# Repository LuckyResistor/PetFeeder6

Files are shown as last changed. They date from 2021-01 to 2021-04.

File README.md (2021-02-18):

# Files for the Pet-Feeder 6 Project

## Details

You will find all details of this project here:

https://luckyresistor.me/projects/lets-print-a-cat-pet-feeding-device/

## License

https://creativecommons.org/licenses/by-sa/4.0/

<br />This work is licensed under a <a rel="license" href="http://creativecommons.org/licenses/by/4.0/">Creative Commons Attribution 4.0 International License</a>.

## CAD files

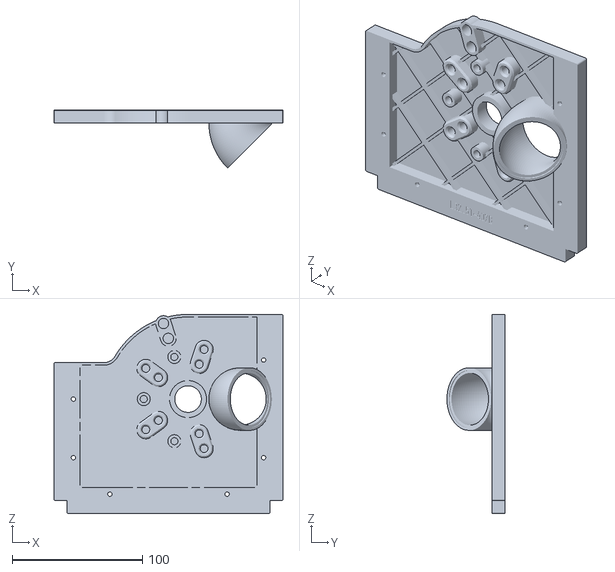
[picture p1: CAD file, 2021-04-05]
mechanics/LR2051-407B.stl
175.8 x 44.6 x 152.9

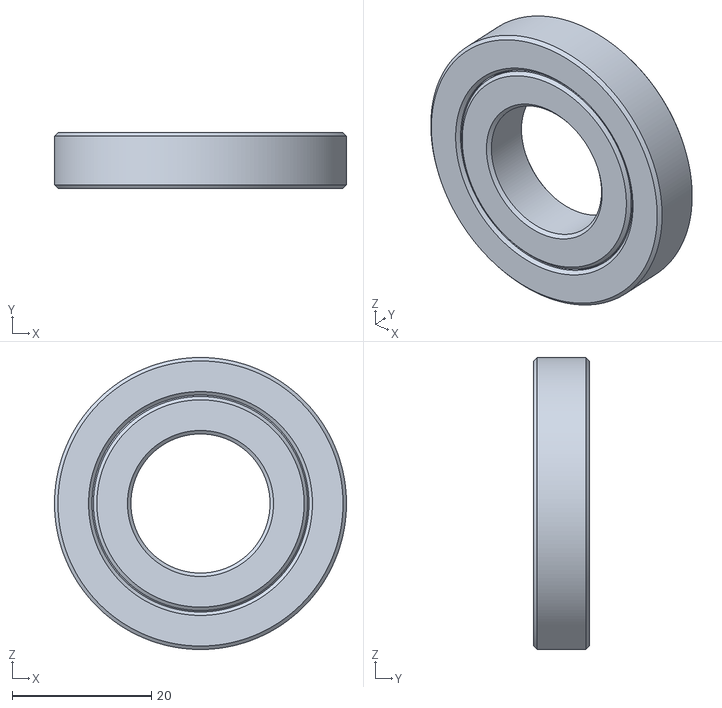
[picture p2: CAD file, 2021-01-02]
mechanics/mockups/LR2051-822.stl
42.0 x 8.00 x 42.0

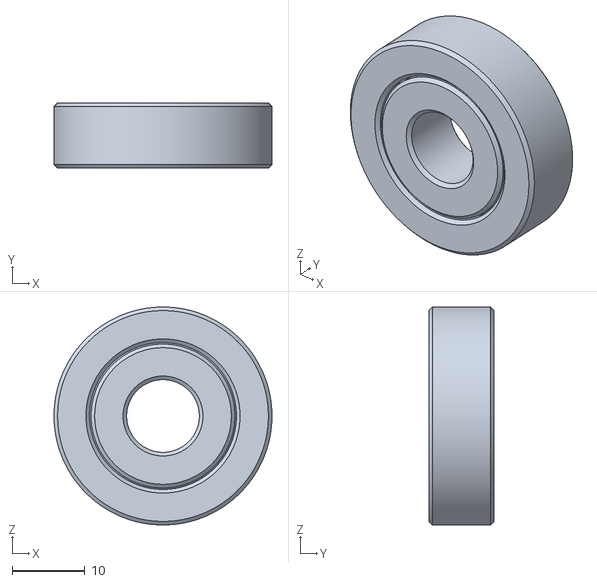
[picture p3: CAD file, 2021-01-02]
mechanics/mockups/LR2051-821.stl
30.0 x 9.00 x 30.0

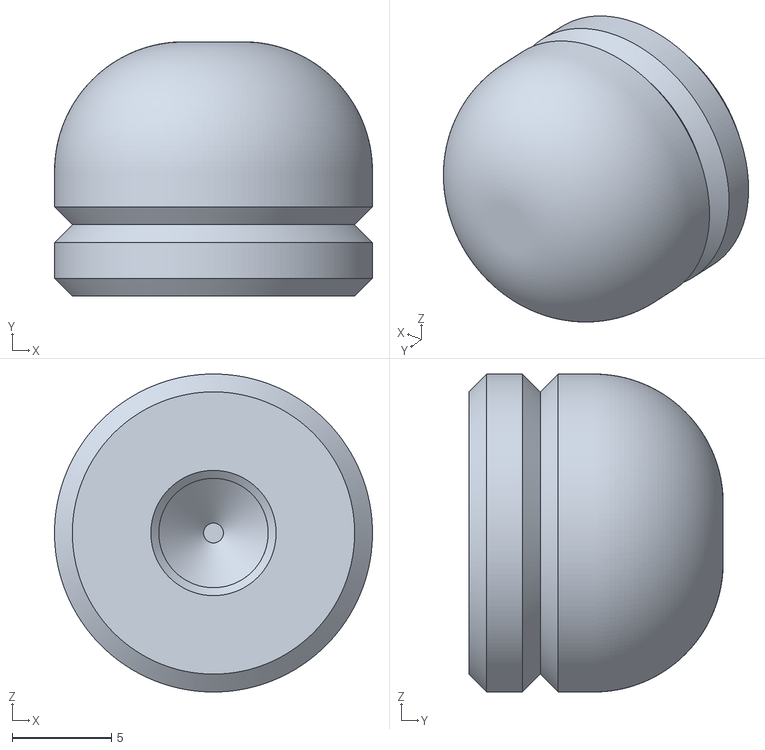
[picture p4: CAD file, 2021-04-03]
mechanics/LR2051-412B.stl
16.0 x 12.8 x 16.0

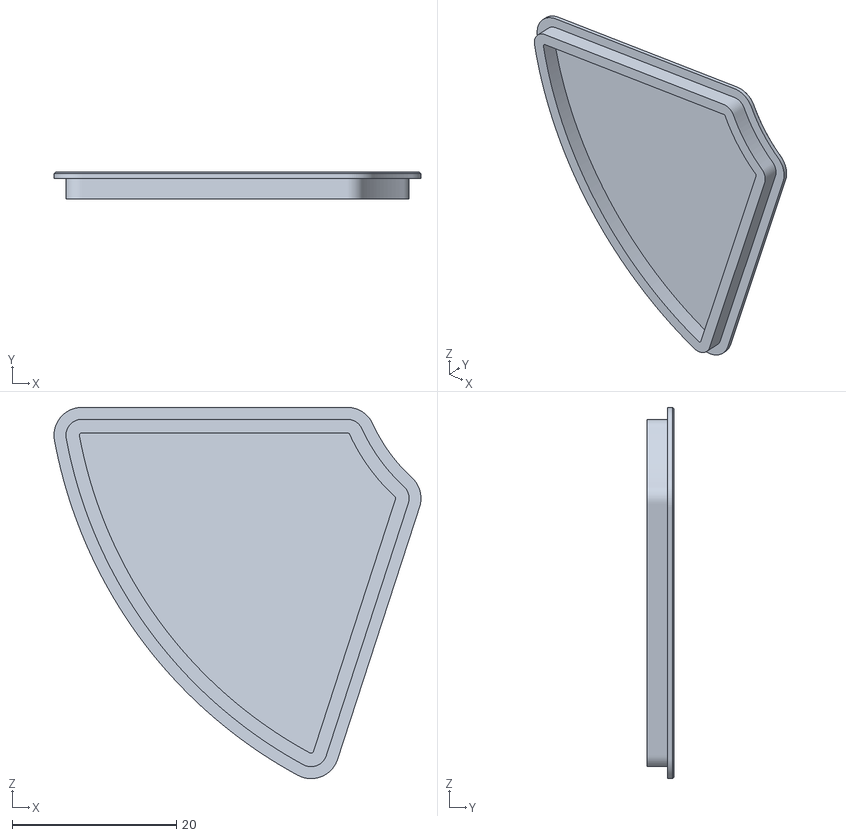
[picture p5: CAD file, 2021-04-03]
mechanics/LR2051-413A.stl
44.6 x 3.30 x 45.1

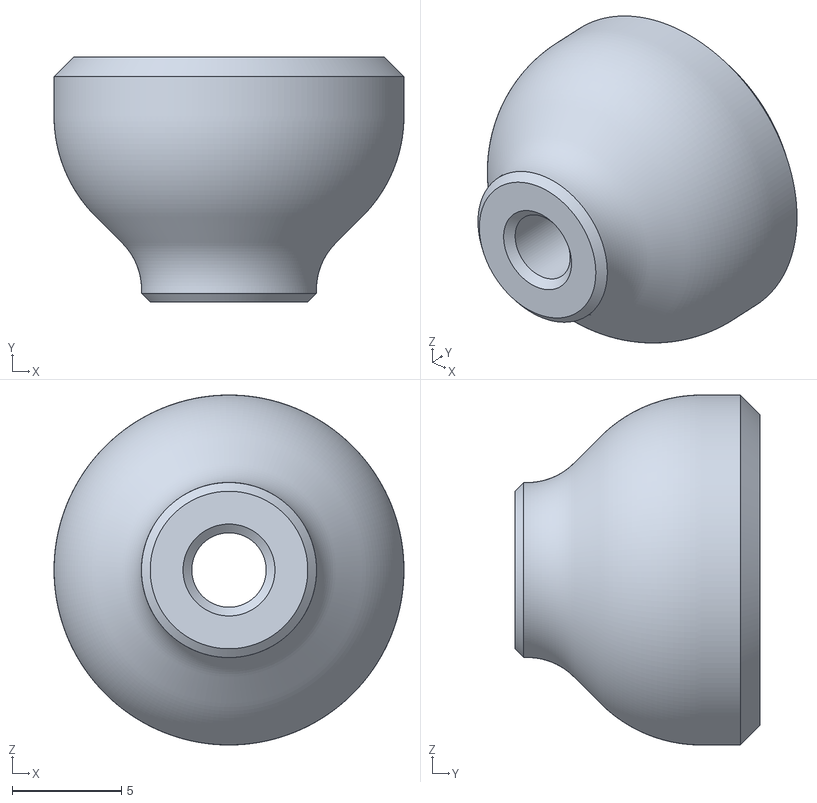
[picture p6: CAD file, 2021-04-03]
mechanics/LR2051-411B.stl
16.0 x 11.2 x 16.0

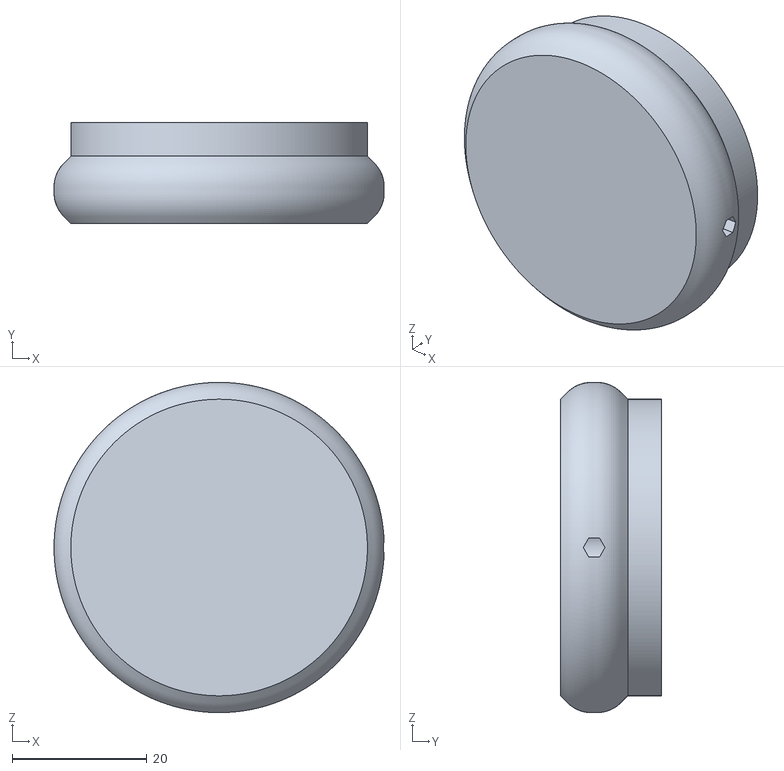
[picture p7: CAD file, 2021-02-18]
mechanics/LR2051-421A.stl
49.0 x 15.0 x 49.0

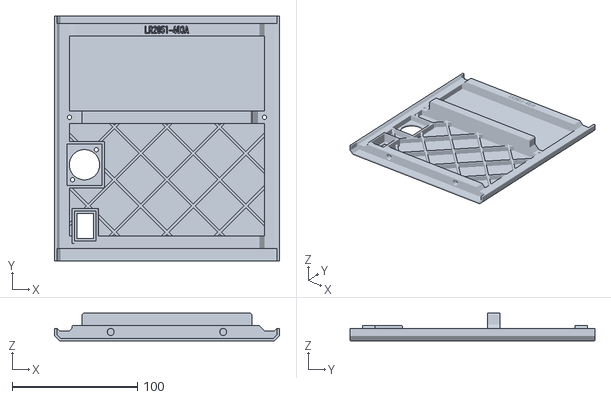
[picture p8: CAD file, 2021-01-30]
mechanics/LR2051-403A.stl
180.0 x 195.9 x 22.0

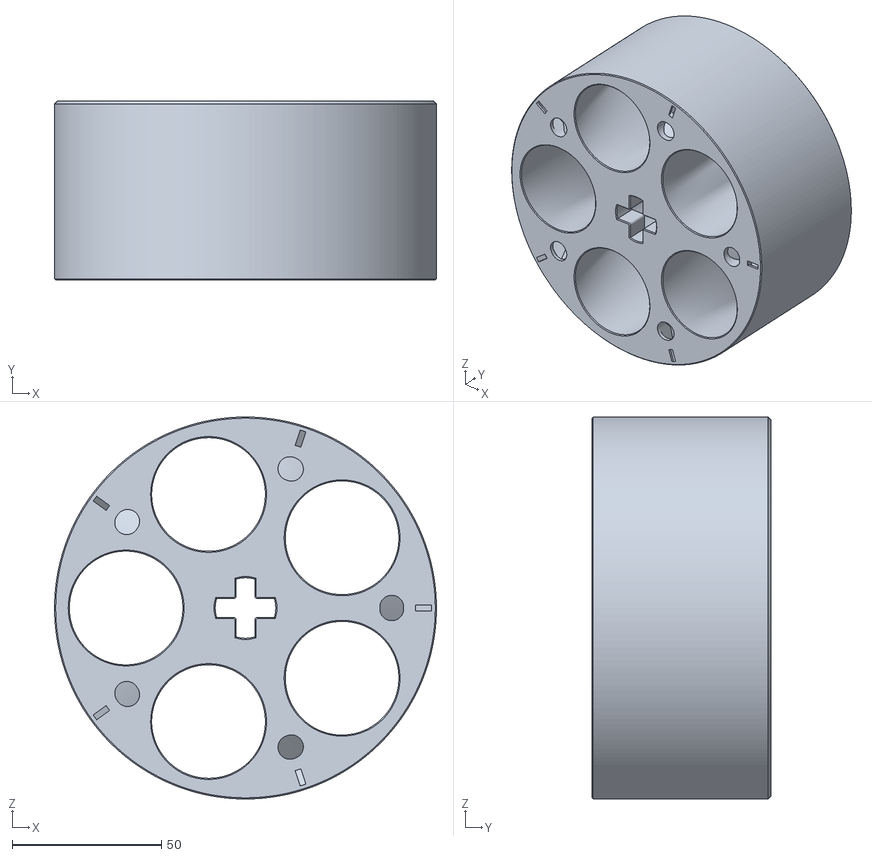
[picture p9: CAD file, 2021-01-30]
mechanics/LR2051-501.stl
128.0 x 60.0 x 128.0

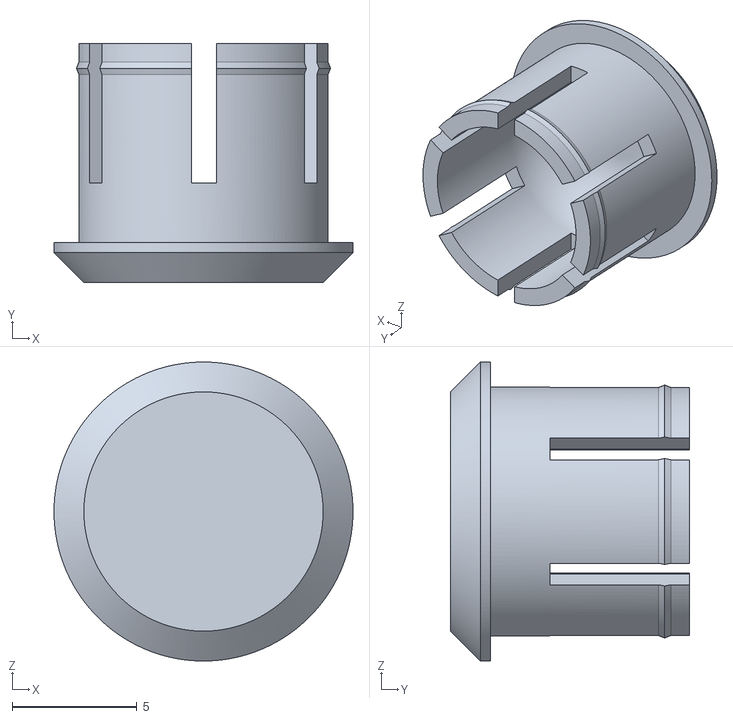
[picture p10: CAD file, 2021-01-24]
mechanics/LR2051-422.stl
12.0 x 9.60 x 12.0

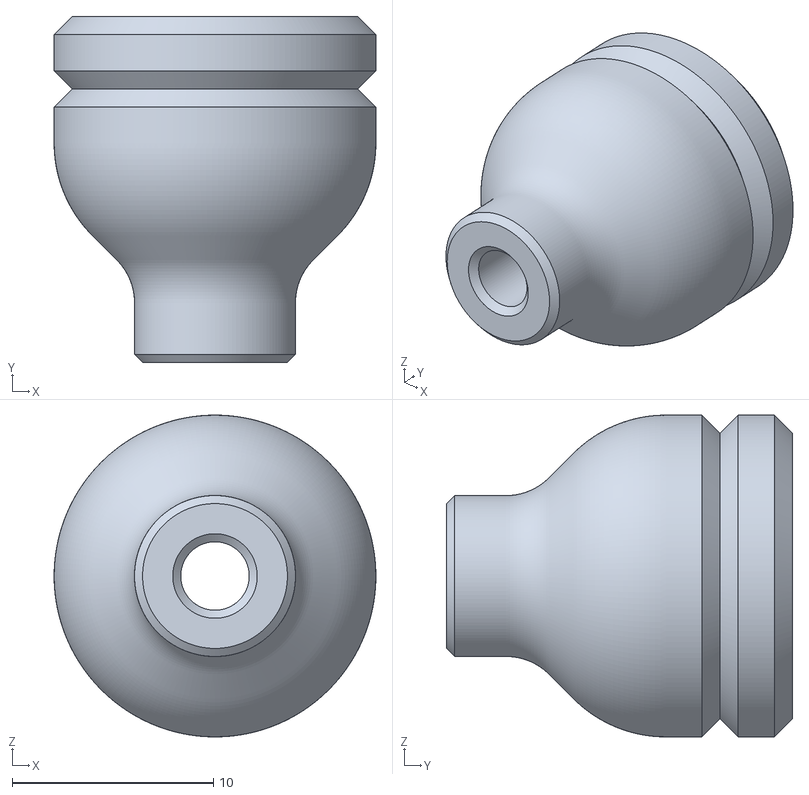
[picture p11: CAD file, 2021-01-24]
mechanics/LR2051-411A.stl
16.0 x 17.2 x 16.0

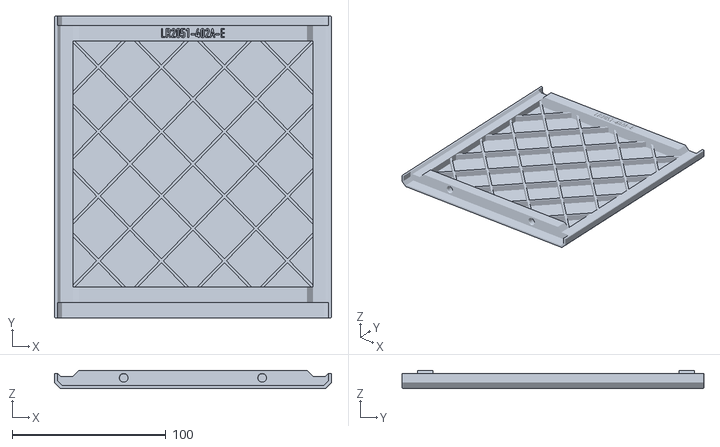
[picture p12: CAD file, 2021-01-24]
mechanics/LR2051-402A-E.stl
180.0 x 195.9 x 12.0

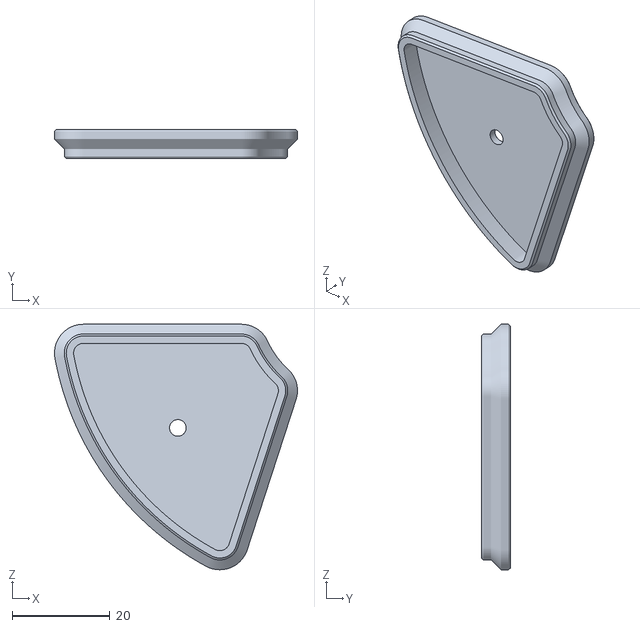
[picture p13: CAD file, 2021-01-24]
mechanics/LR2051-409A.stl
49.6 x 6.00 x 50.1

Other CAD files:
slicer-files/LR2051-407B.3mf
mechanics/LR2051-407E.stl
slicer-files/LR2051-407E.3mf
mechanics/LR2051-403A-E.stl
mechanics/LR2051-402A-ND.stl
mechanics/LR2051-101B.stl
mechanics/LR2051-102B.stl
mechanics/LR2051-103B.stl
mechanics/LR2051-104B.stl
mechanics/LR2051-105B.stl
mechanics/LR2051-107B.stl
mechanics/LR2051-108B.stl
mechanics/LR2051-111B.stl
mechanics/LR2051-112B.stl
mechanics/LR2051-121.stl
mechanics/LR2051-122.stl
mechanics/LR2051-123.stl
mechanics/LR2051-124.stl
mechanics/LR2051-401A.stl
mechanics/LR2051-402A.f3d
mechanics/LR2051-402A.stl
mechanics/LR2051-403A.f3d
mechanics/LR2051-404A.stl
mechanics/LR2051-405A.stl
mechanics/LR2051-406A.stl
mechanics/LR2051-407A.stl
mechanics/LR2051-408A.stl
mechanics/LR2051-412A.stl
mechanics/mockups/LR2051-821.f3d
mechanics/mockups/LR2051-822.f3d
mechanics/old-revisions/LR2051-407A.stl
mechanics/old-revisions/LR2051-412A.stl

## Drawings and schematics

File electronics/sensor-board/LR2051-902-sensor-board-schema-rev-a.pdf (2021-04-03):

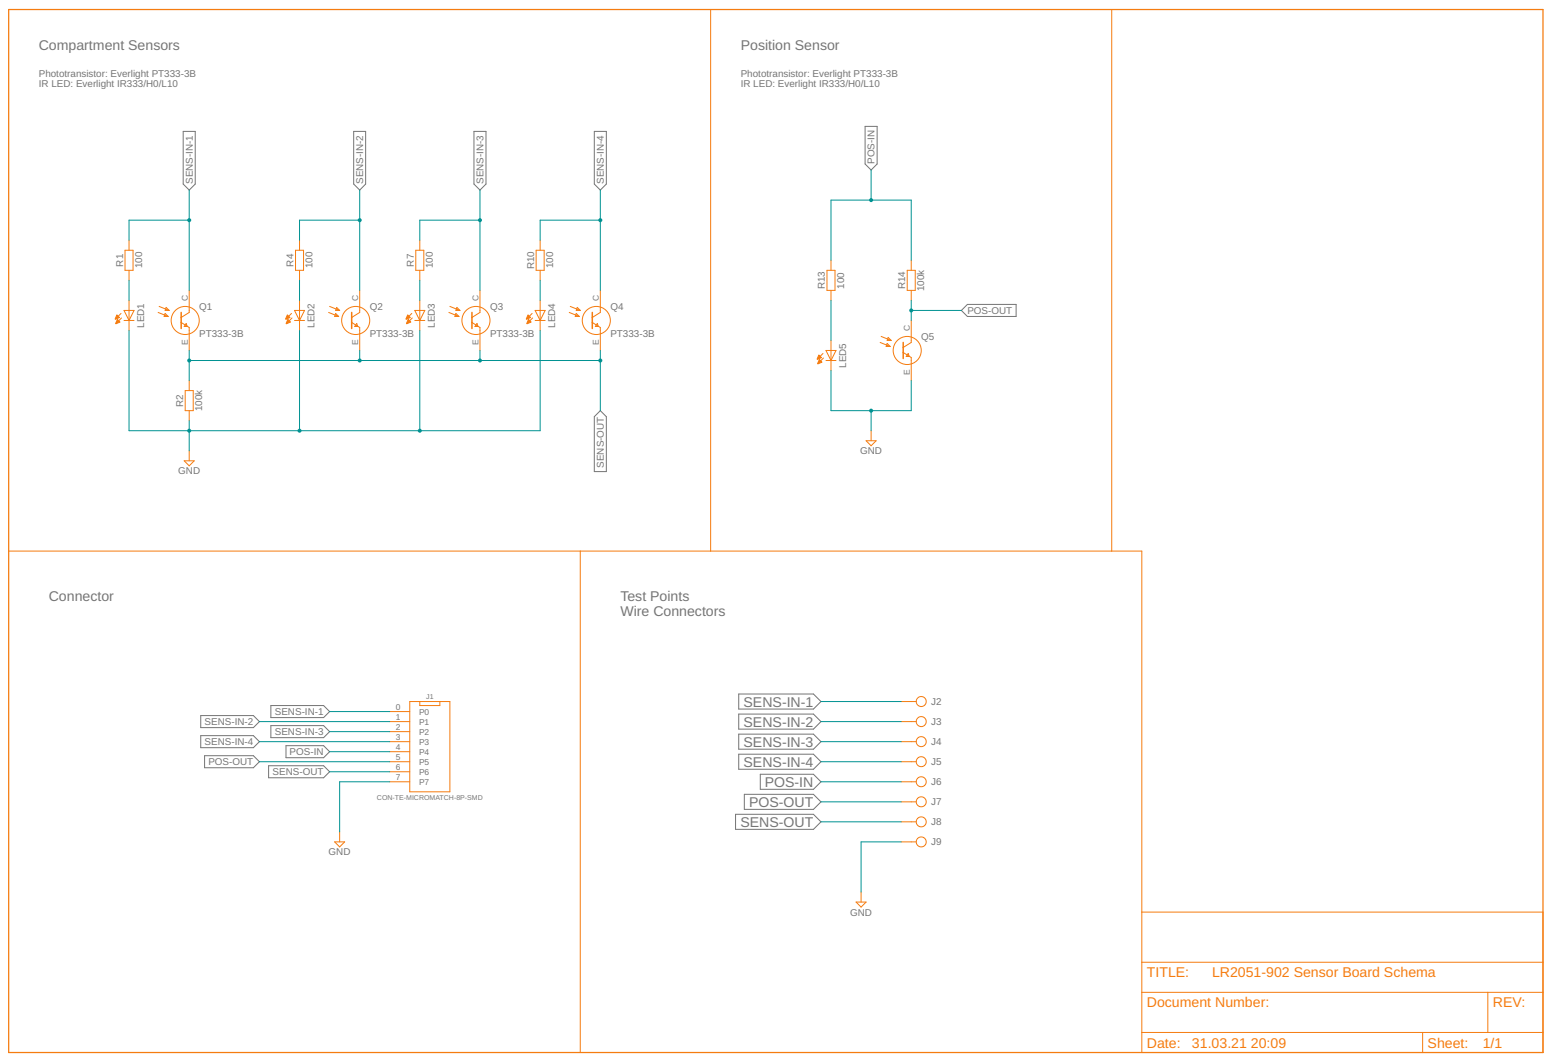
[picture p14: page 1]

SENS-IN-1

CON-TE-MICROMATCH-8P-SMD GND

Document Number: | REV:

Date: 31.03.21 20:09 | Sheet: 1/1

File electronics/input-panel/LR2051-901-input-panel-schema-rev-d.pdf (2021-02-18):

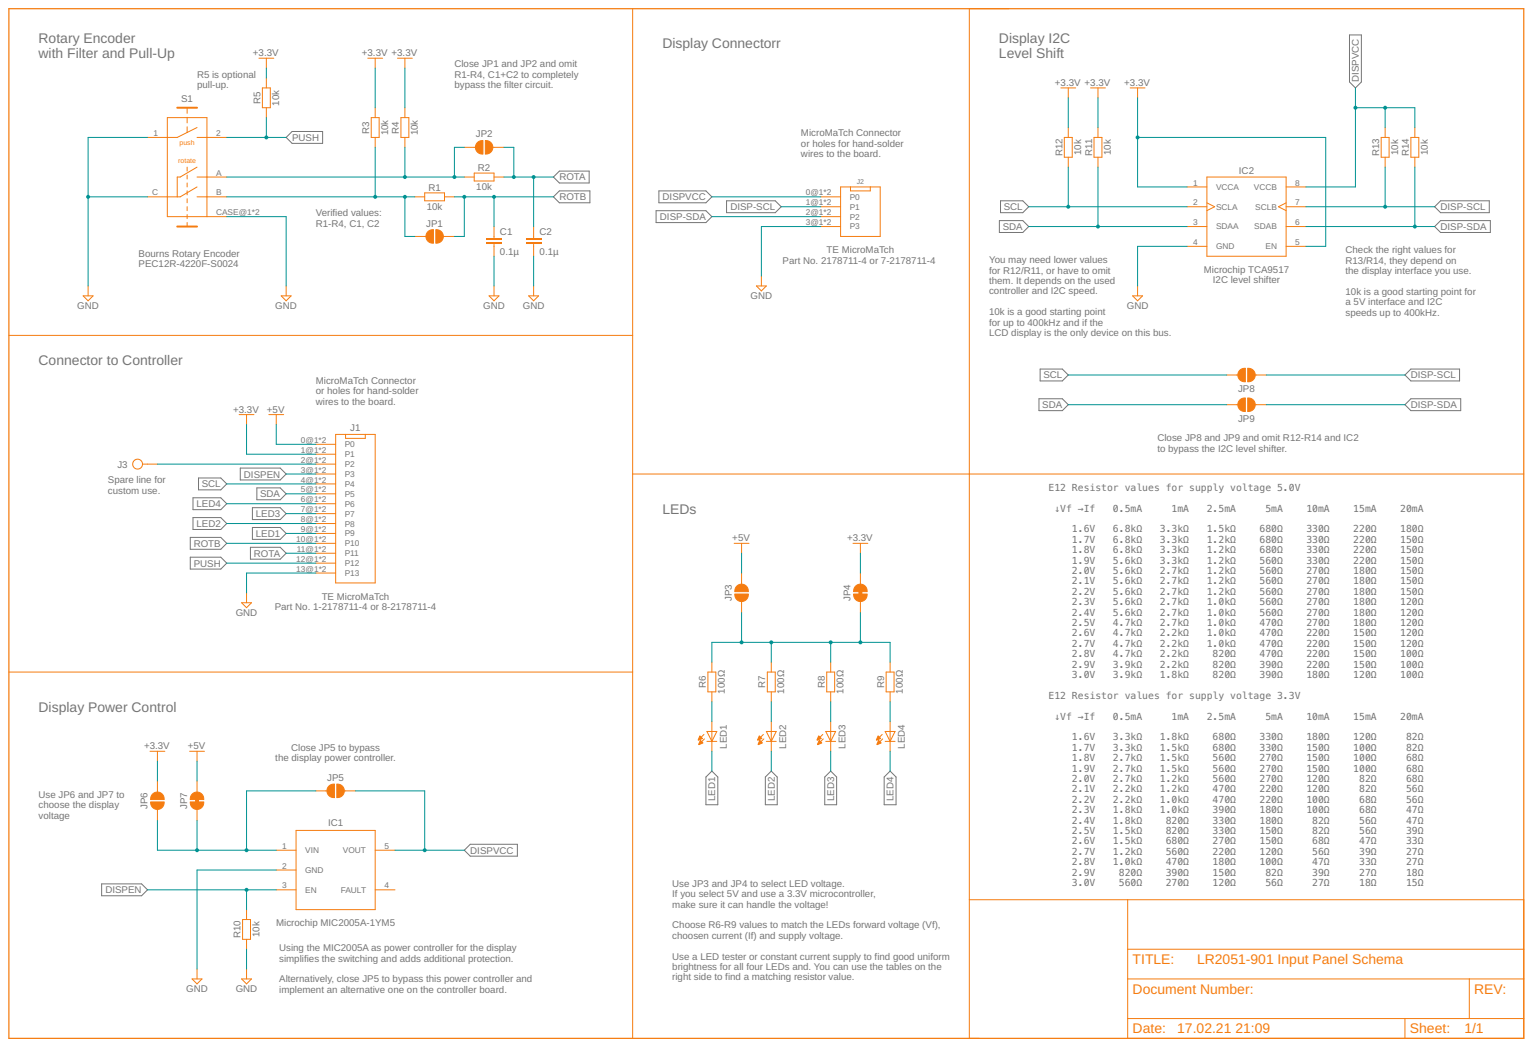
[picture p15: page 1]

Rotary Encoder
with Filter and Pull-Up

Close JP1 and JP2 and omit
R1-R4, C1+C2 to completely

bypass the filter circuit. R5 is optional
pull-up.

MicroMaTch Connector or holes for hand-solder wires to the board.

Check the right values for R13/R14, they depend on
the display interface you use. 10k is a good starting point for a 5V interface and I2C

I2C level shifter You may need lower values
for R12/R11, or have to omit
them. It depends on the used
controller and I2C speed. 10k is a good starting point

for up to 400kHz and if the
LCD display is the only device on this bus.

MicroMaTch Connector or holes for hand-solder wires to the board. Spare line for custom use.

Close JP8 and JP9 and omit R12-R14 and IC2
to bypass the I2C level shifter.

E12 Resistor values for supply voltage 5.0V
E12 Resistor values for supply voltage 3.3V

Close JP5 to bypass
the display power controller.

Use JP3 and JP4 to select LED voltage.
If you select 5V and use a 3.3V microcontroller, make sure it can handle the voltage!

Choose R6-R9 values to match the LEDs forward voltage (Vf), choosen current (If) and supply voltage. Use a LED tester or constant current supply to find good uniform

Using the MIC2005A as power controller for the display
simplifies the switching and adds additional protection. Alternatively, close JP5 to bypass this power controller and

brightness for all four LEDs and. You can use the tables on the
right side to find a matching resistor value.

implement an alternative one on the controller board.

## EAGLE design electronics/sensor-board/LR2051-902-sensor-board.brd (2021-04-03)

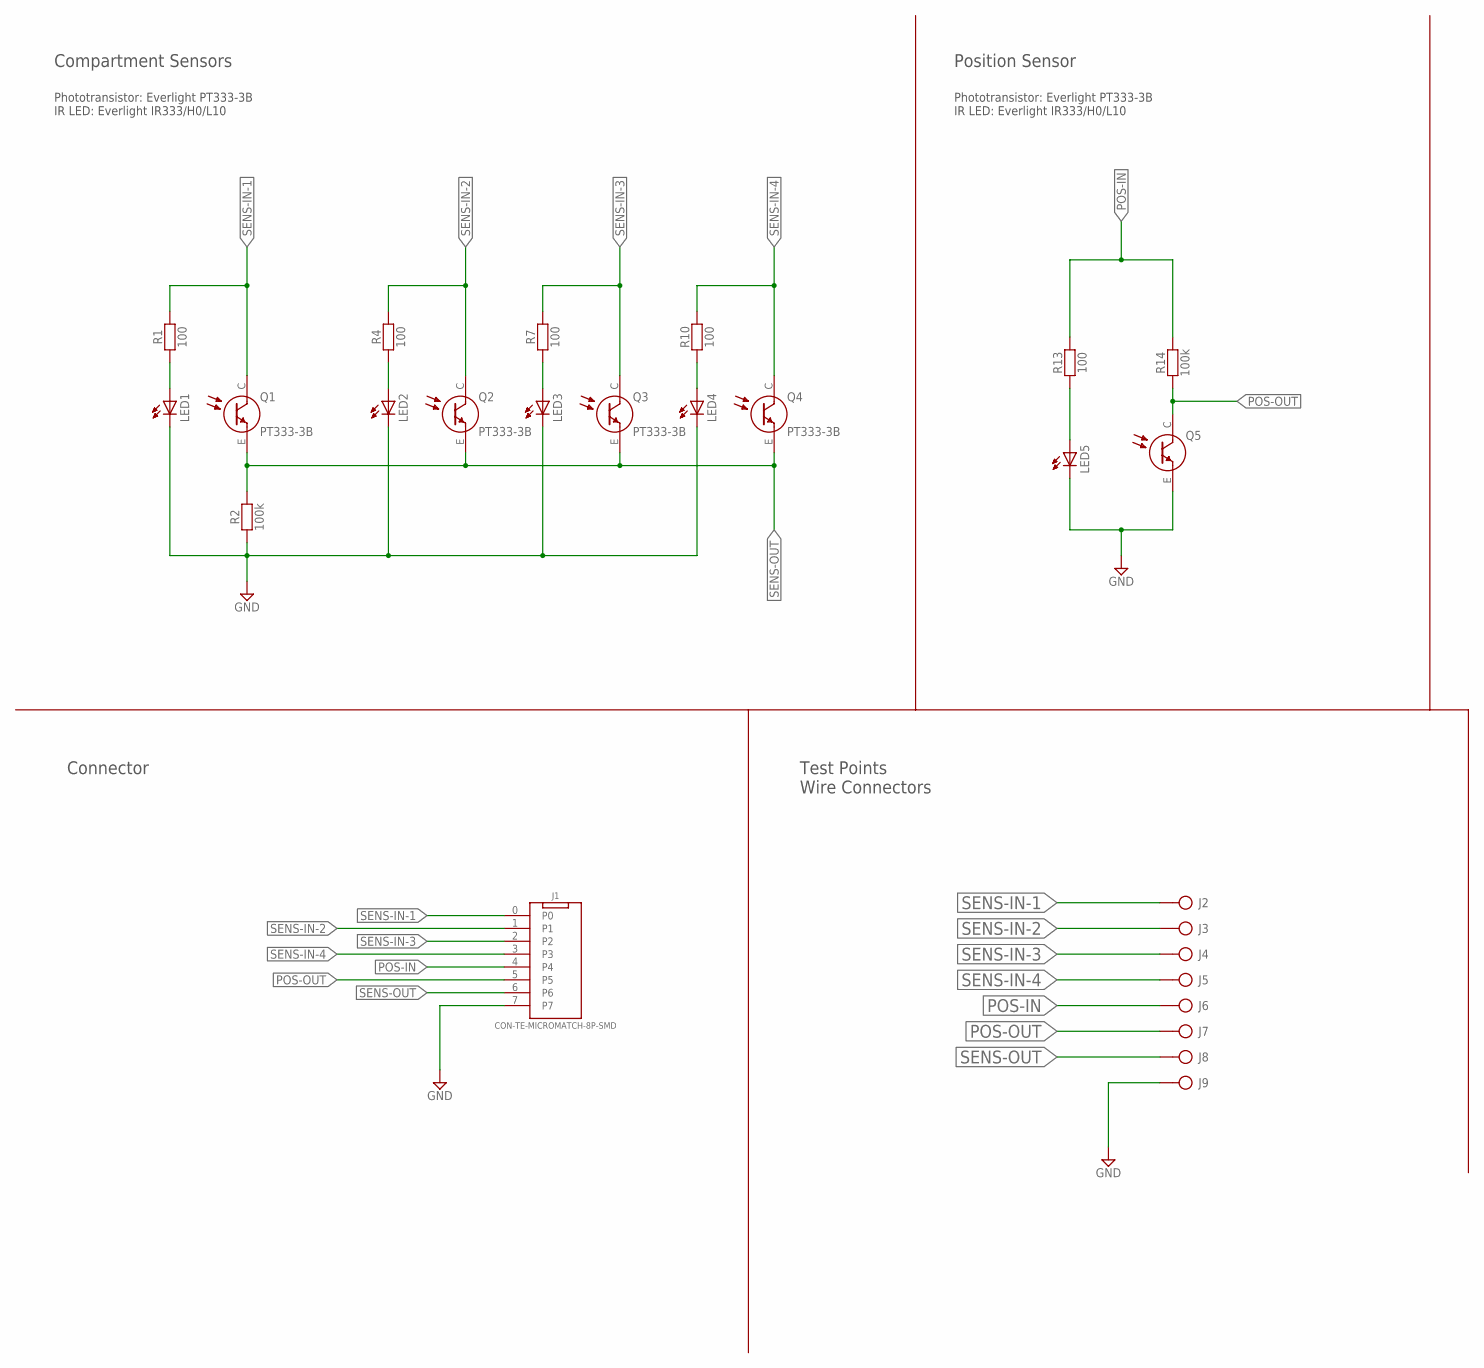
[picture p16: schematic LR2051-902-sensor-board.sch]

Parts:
J1: CON-TE-MICROMATCH-8P-SMD; CON-TE-MICROMATCH-2178711-8
J2, J3, J4, J5, J6, J7, J8, J9: CON-HOLE-D0.9
LED1, LED2, LED3, LED4, LED5: LED5MM
Q1, Q2, Q3, Q4: PT333-3B; Q-PHOTO-2P-TH-5MM
Q5: Q-PHOTO-TH-5MM; Q-PHOTO-2P-TH-5MM
R1, R4, R7, R10, R13: 100; R-0805-HANDSOLDER
R2, R14: 100k; R-0805-HANDSOLDER

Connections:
GND: J1.7, J9.1, LED1.K (C), LED2.K (C), LED3.K (C), LED4.K (C), LED5.K (C), Q5.E, R2.1
unnamed: LED1.A, R1.1
unnamed: LED2.A, R4.1
unnamed: LED3.A, R7.1
unnamed: LED4.A, R10.1
unnamed: LED5.A, R13.1
POS-IN: J1.4, J6.1, R13.2, R14.2
POS-OUT: J1.5, J7.1, Q5.C, R14.1
SENS-IN-1: J1.0, J2.1, Q1.C, R1.2
SENS-IN-2: J1.1, J3.1, Q2.C, R4.2
SENS-IN-3: J1.2, J4.1, Q3.C, R7.2
SENS-IN-4: J1.3, J5.1, Q4.C, R10.2
SENS-OUT: J1.6, J8.1, Q1.E, Q2.E, Q3.E, Q4.E, R2.2

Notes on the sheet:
Compartment Sensors
Position Sensor
Connector
Test Points Wire Connectors
Phototransistor: Everlight PT333-3B IR LED: Everlight IR333/H0/L10

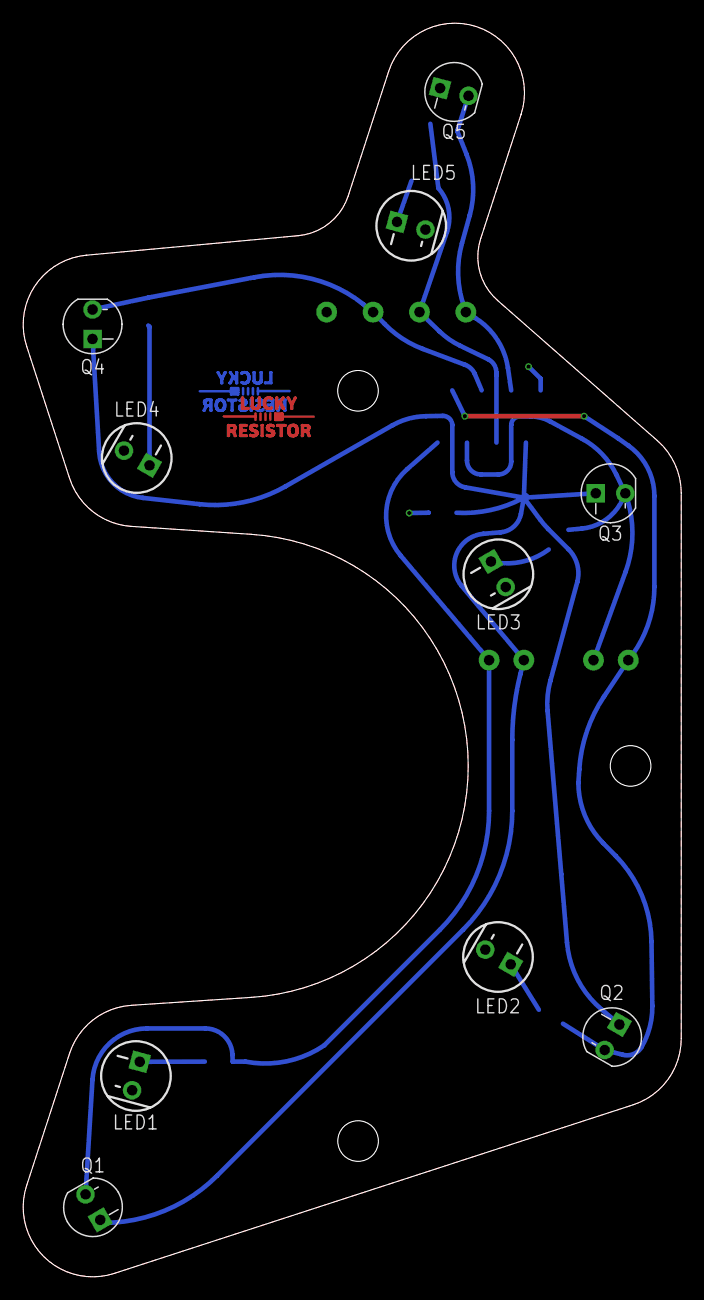
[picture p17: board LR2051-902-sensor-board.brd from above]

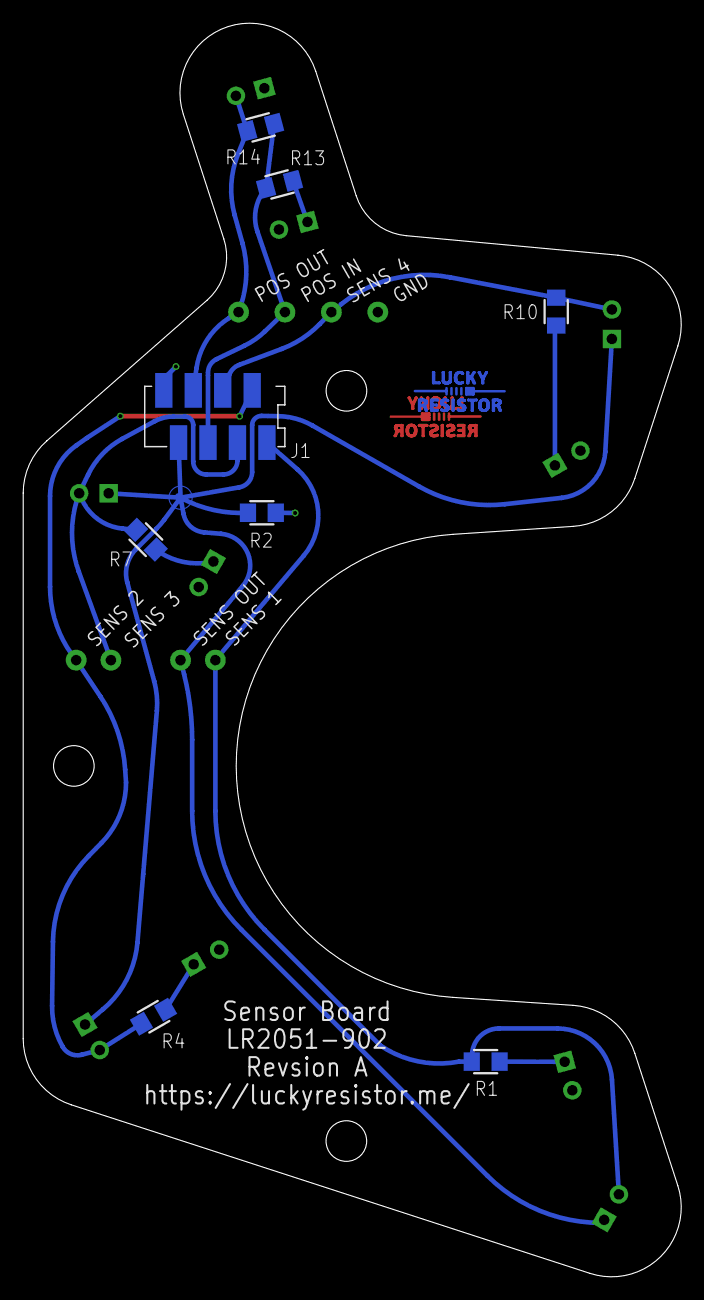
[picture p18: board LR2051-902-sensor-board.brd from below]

Board: 2 copper layers, 56.7 x 108.1 mm, 28 parts (17 on the bottom side), 13 nets.

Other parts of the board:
U$1, U$2: LR_LOGO_COPPER_8MM_NOMASK

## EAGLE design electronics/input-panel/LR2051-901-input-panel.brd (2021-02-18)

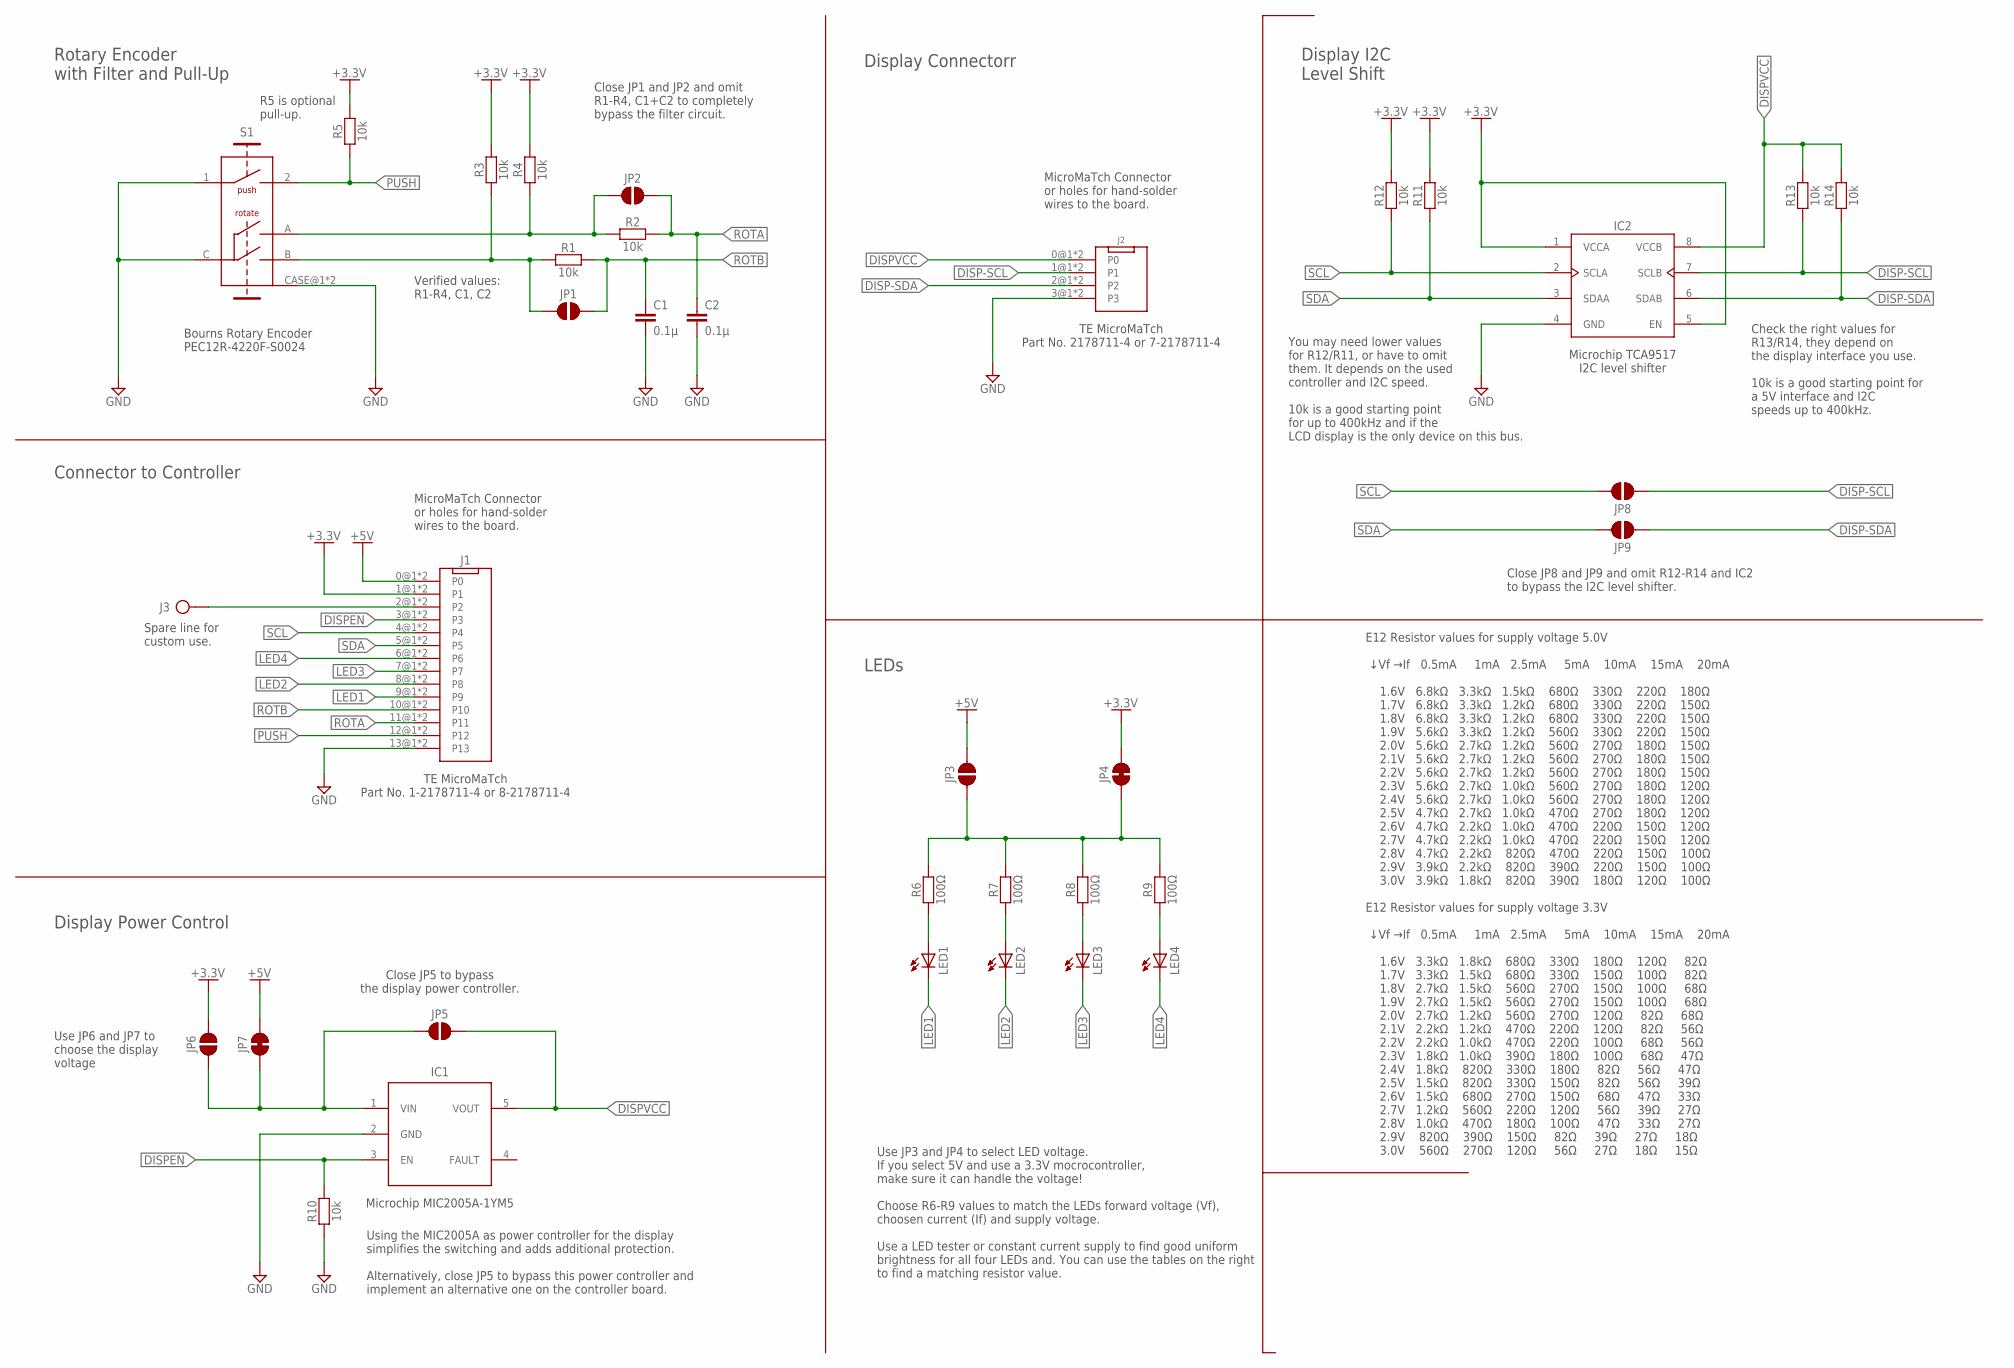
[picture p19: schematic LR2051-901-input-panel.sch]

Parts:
C1, C2: 0.1µ; CAPACITOR-0805-VISHAY
IC1: IC-MIC2005A-1YM5; SOT23-5
IC2: IC-TCA9517; SOIC127P599X175-8N
J1: CON-TE-MICROMATCH-14P-SMD+TH; CON-TE-MICROMATCH-1-2178711-4+TH
J2: CON-TE-MICROMATCH-4P-SMD+TH; CON-TE-MICROMATCH-2178711-4+TH
J3: CON-HOLE-D0.9
JP1, JP2, JP3, JP5, JP6, JP8, JP9: J-SMD-OFF
JP4, JP7: J-SMD-ON
LED1, LED2, LED3, LED4: LED5MM
R1, R2, R3, R4, R5, R10, R11, R12, R13, R14: 10k; R-0805-HANDSOLDER
R6, R7, R8, R9: 100Ω; R-0805-HANDSOLDER
S1: ENC-BOURNS-PEC12R-4220F-S0024

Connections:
+3.3V: IC2.1 (VCCA), IC2.5 (EN), J1.1@1 (P1), J1.1@2 (P1), JP4.2, JP6.2, R3.2, R4.2, R5.2, R11.2, R12.2
+5V: J1.0@1 (P0), J1.0@2 (P0), JP3.2, JP7.2
DISP-SCL: IC2.7 (SCLB), J2.1@1 (P1), J2.1@2 (P1), JP8.1, R13.1
DISP-SDA: IC2.6 (SDAB), J2.2@1 (P2), J2.2@2 (P2), JP9.1, R14.1
DISP-VIN: IC1.1 (VIN), JP5.1, JP6.1, JP7.1
DISPEN: IC1.3 (EN), J1.3@1 (P3), J1.3@2 (P3), R10.2
DISPVCC: IC1.5 (VOUT), IC2.8 (VCCB), J2.0@1 (P0), J2.0@2 (P0), JP5.2, R13.2, R14.2
GND: C1.2, C2.2, IC1.2 (GND), IC2.4 (GND), J1.13@1 (P13), J1.13@2 (P13), J2.3@1 (P3), J2.3@2 (P3), R10.1, S1.1 (S), S1.C, S1.CASE@1 (GND), S1.CASE@2 (GND)
LED1: J1.9@1 (P9), J1.9@2 (P9), LED1.K (C)
LED2: J1.8@1 (P8), J1.8@2 (P8), LED2.K (C)
LED3: J1.7@1 (P7), J1.7@2 (P7), LED3.K (C)
LED4: J1.6@1 (P6), J1.6@2 (P6), LED4.K (C)
LED-VCC: JP3.1, JP4.1, R6.2, R7.2, R8.2, R9.2
unnamed: JP1.1, R1.1, R3.1, S1.B
unnamed: J1.2@1 (P2), J1.2@2 (P2), J3.1
unnamed: JP2.1, R2.1, R4.1, S1.A
unnamed: LED1.A, R6.1
unnamed: LED2.A, R7.1
unnamed: LED3.A, R8.1
unnamed: LED4.A, R9.1
PUSH: J1.12@1 (P12), J1.12@2 (P12), R5.1, S1.2 (S)
ROTA: C2.1, J1.11@1 (P11), J1.11@2 (P11), JP2.2, R2.2
ROTB: C1.1, J1.10@1 (P10), J1.10@2 (P10), JP1.2, R1.2
SCL: IC2.2 (SCLA), J1.4@1 (P4), J1.4@2 (P4), JP8.2, R12.1
SDA: IC2.3 (SDAA), J1.5@1 (P5), J1.5@2 (P5), JP9.2, R11.1

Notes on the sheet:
Rotary Encoder with Filter and Pull-Up
Connector to Controller
LEDs
Display Power Control
Display I2C Level Shift
Display Connectorr
MicroMaTch Connector or holes for hand-solder wires to the board.
Spare line for custom use.
Close JP1 and JP2 and omit R1-R4, C1+C2 to completely bypass the filter circuit.
R5 is optional pull-up.
Bourns Rotary Encoder PEC12R-4220F-S0024
Use JP3 and JP4 to select LED voltage. If you select 5V and use a 3.3V mocrocontroller, make sure it can handle the voltage\! Choose R6-R9 values to match the LEDs forward voltage (Vf), choosen current (If) and supply voltage. Use a LED tester or constant current supply to find good uniform brightn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
Microchip TCA9517 I2C level shifter
You may need lower values for R12/R11, or have to omit them. It depends on the used controller and I2C speed. 10k is a good starting point for up to 400kHz and if the LCD display is the only device on this bus.
Check the right values for R13/R14, they depend on the display interface you use. 10k is a good starting point for a 5V interface and I2C speeds up to 400kHz.
Close JP8 and JP9 and omit R12-R14 and IC2 to bypass the I2C level shifter.
TE MicroMaTch Part No. 1-2178711-4 or 8-2178711-4
TE MicroMaTch Part No. 2178711-4 or 7-2178711-4
Use JP6 and JP7 to choose the display voltage
Close JP5 to bypass the display power controller.
Microchip MIC2005A-1YM5
Using the MIC2005A as power controller for the display simplifies the switching and adds additional protection. Alternatively, close JP5 to bypass this power controller and implement an alternative one on the controller board.
Verified values: R1-R4, C1, C2
E12 Resistor values for supply voltage 3.3V ↓Vf →If 0.5mA 1mA 2.5mA 5mA 10mA 15mA 20mA 1.6V 3.3kΩ 1.8kΩ 680Ω 330Ω 180Ω 120Ω 82Ω 1.7V 3.3kΩ 1.5kΩ 680Ω 330Ω 150Ω 100Ω 82Ω 1.8V 2.7kΩ 1.5kΩ 560Ω 270Ω 150Ω 100Ω 68Ω 1.9V 2.7kΩ 1.5kΩ 560Ω 270Ω 150Ω 100Ω 68Ω 2.0V 2.7kΩ 1.2kΩ 560Ω 270Ω 120Ω 82Ω 68Ω 2.1V 2.2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
E12 Resistor values for supply voltage 5.0V ↓Vf →If 0.5mA 1mA 2.5mA 5mA 10mA 15mA 20mA 1.6V 6.8kΩ 3.3kΩ 1.5kΩ 680Ω 330Ω 220Ω 180Ω 1.7V 6.8kΩ 3.3kΩ 1.2kΩ 680Ω 330Ω 220Ω 150Ω 1.8V 6.8kΩ 3.3kΩ 1.2kΩ 680Ω 330Ω 220Ω 150Ω 1.9V 5.6kΩ 3.3kΩ 1.2kΩ 560Ω 330Ω 220Ω 150Ω 2.0V 5.6kΩ 2.7kΩ 1.2kΩ 560Ω 270Ω 180Ω 15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

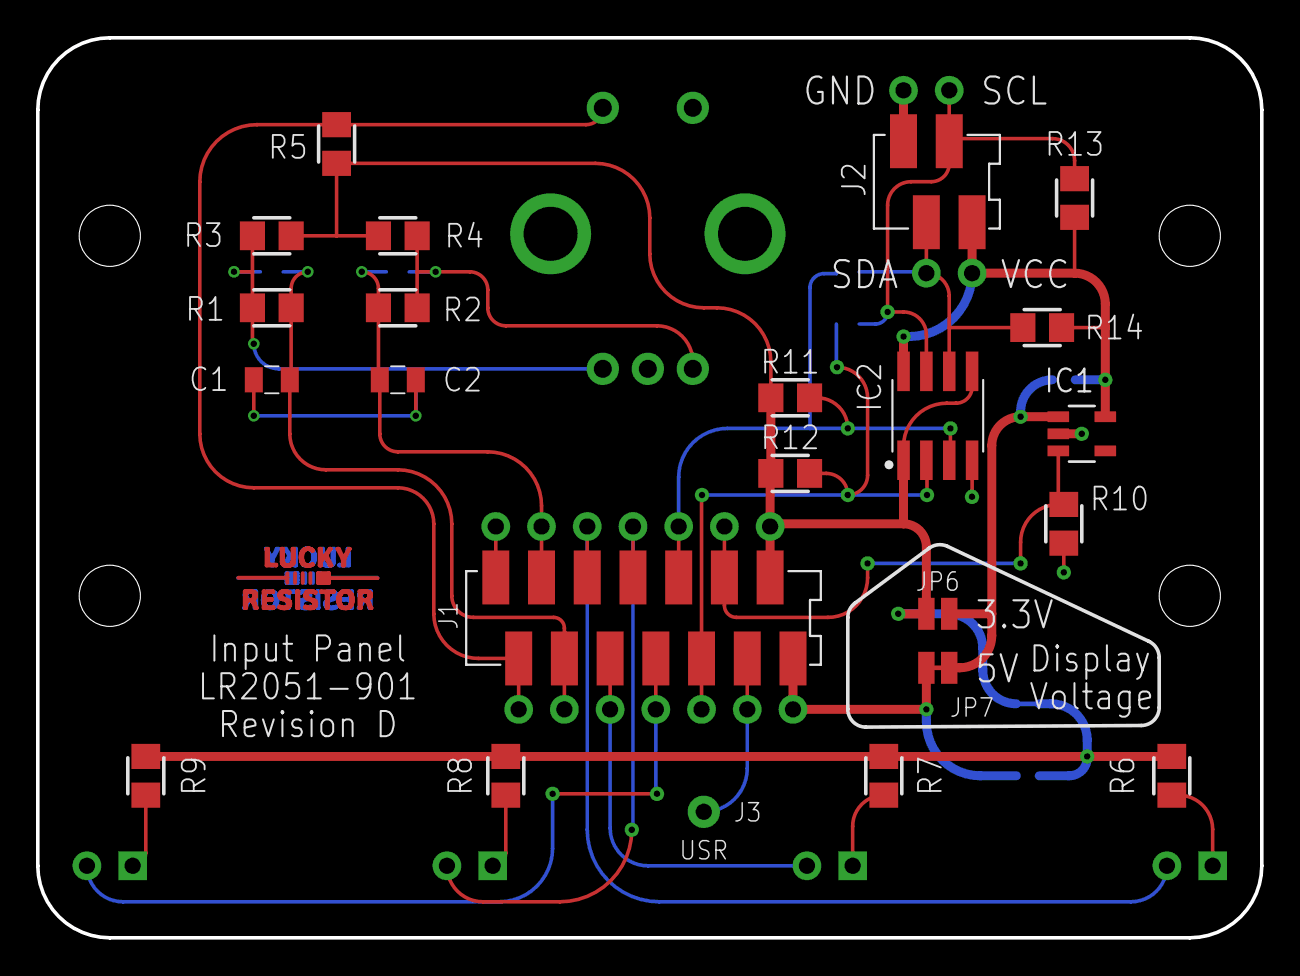
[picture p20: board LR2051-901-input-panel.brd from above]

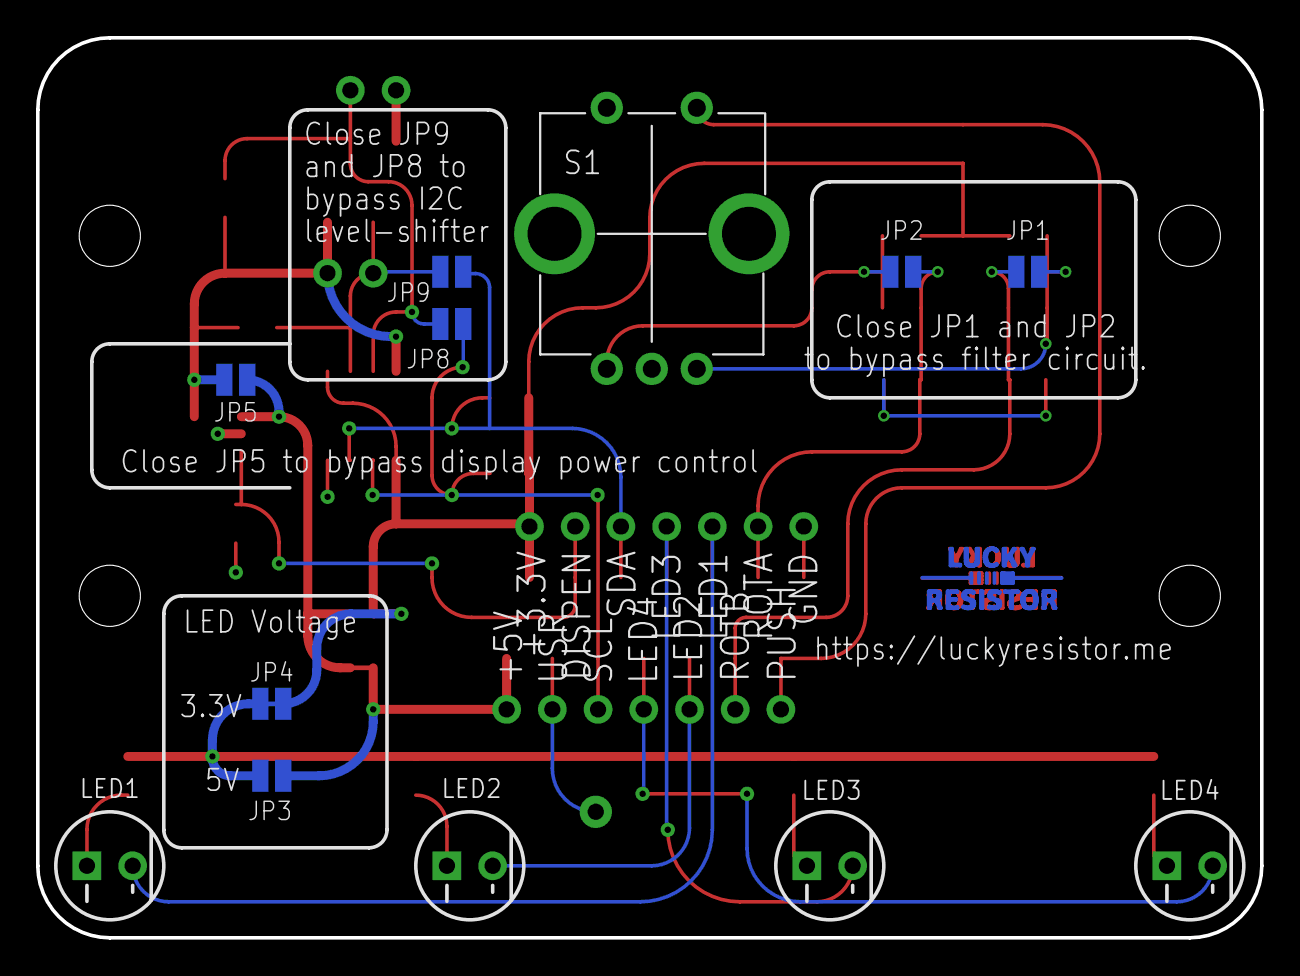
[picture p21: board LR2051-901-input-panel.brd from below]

Board: 2 copper layers, 68.0 x 50.0 mm, 37 parts (13 on the bottom side), 25 nets.

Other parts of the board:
U$1, U$2: LR_LOGO_COPPER_8MM_NOMASK

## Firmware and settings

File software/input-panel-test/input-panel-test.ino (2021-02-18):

//
// Pet Feeder Input Panel Demo
// ====================================================================================
// Copyright (c)2021 by Lucky Resistor. https://luckyresistor.me/
//


#include <Arduino.h>
#include <Wire.h>
#include <Adafruit_LiquidCrystal.h>

#include <cstdint>


// Create an instance of the LCD driver.
Adafruit_LiquidCrystal lcd(0);

// Input events
enum class Input : uint8_t {
  None = 0, // No input 
  Push, // Push button pressed.
  Left, // Rotated left
  Right // Rotated right
};


// The connections from the input panel to the pins of the MCU.
//
const uint8_t statusLed = 13;
const uint8_t led1 = 5;
const uint8_t led2 = 6;
const uint8_t led3 = 10;
const uint8_t led4 = 11;
const uint8_t displayEnable = 12;
const uint8_t buttonPush = 9;
const uint8_t buttonRotB = 0;
const uint8_t buttonRotA = 1;

// Array to address the LEDs via index
const uint8_t leds[] = {led1, led2, led3, led4};

// Working set:

// The last state of the rotary encoder.
uint8_t lastRotaryState = 0;
// The sequence of the last rotary states.
uint8_t lastRotaryStates[4];
// The last state of the push button.
bool lastPushButtonState = false;
// The time when the push button was pressed.
uint32_t pushButtonPressedTime = 0;

// The maximum number of input events.
const uint8_t inputMaximum = 32;
// An array with the last 32 input events.
Input inputs[inputMaximum];
// The current number of input events.
volatile uint8_t inputCount = 0;

// Counter for the demo.
uint32_t counter = 0;

// Enable the LED at the given index.
//
void setLedEnabled(uint8_t ledIndex, bool enabled) {
  const auto pin = leds[ledIndex];
  if (enabled) {
    digitalWrite(pin, LOW);
    pinMode(pin, OUTPUT);
  } else {
    digitalWrite(pin, LOW);
    pinMode(pin, INPUT);
  }
}


// Push an input event in the queue.
//
void pushInput(Input input)
{
  if (inputCount < inputMaximum) {
    inputs[inputCount] = input;
    inputCount += 1;
  }
}

// Check for inputs.
//
Input getInput()
{
  noInterrupts();
  Input result = Input::None;
  if (inputCount > 0) {
    result = inputs[0];
    memmove(inputs, inputs+1, inputMaximum-1);
    inputCount -= 1;
  }
  interrupts();
  return result;
}


// Get the current state of the rotary encoder.
//
uint8_t getRotaryState()
{
  const bool rotA = (digitalRead(buttonRotA) == LOW);
  const bool rotB = (digitalRead(buttonRotB) == LOW);
  return (rotA ? 0b01 : 0b00) | (rotB ? 0b10 : 0b00);
}


// Get the current state of the push button.
//
uint8_t getPushButtonState()
{
  return (digitalRead(buttonPush) == LOW);
}


// Process the button states everytime the signal changes on one of the inputs.
//
void processButtons()
{
  const uint8_t rotaryState = getRotaryState();
  if (lastRotaryState != rotaryState) {
    lastRotaryState = rotaryState;
    // It has moved. Push this state into the array
    lastRotaryStates[3] = lastRotaryStates[2];
    lastRotaryStates[2] = lastRotaryStates[1];
    lastRotaryStates[1] = lastRotaryStates[0];
    lastRotaryStates[0] = rotaryState;
    // If we reached the zero state, check if we made a proper rotation.
    if (rotaryState == 0b00) {
      if (lastRotaryStates[1] == 0b10 && lastRotaryStates[2] == 0b11 && lastRotaryStates[3] == 0b01) {
        pushInput(Input::Left);
      } else if (lastRotaryStates[1] == 0b01 && lastRotaryStates[2] == 0b11 && lastRotaryStates[3] == 0b10) {
        pushInput(Input::Right);
      }
    }

    // display the rotary input
    setLedEnabled(1, (rotaryState & 0b01) != 0);
    setLedEnabled(2, (rotaryState & 0b10) != 0);
  }

  const bool pushButtonState = getPushButtonState();
  if (pushButtonState != lastPushButtonState) {
    lastPushButtonState = pushButtonState;
    if (pushButtonState) {
      // pushed, note the time.
      pushButtonPressedTime = millis();
    } else {
      // released
      const int32_t duration = static_cast<int32_t>(millis() - pushButtonPressedTime);
      if (duration > 50 && duration < 2000) {
        // valid button press.
        pushInput(Input::Push);
      }
    }
    // display button input.
    setLedEnabled(3, pushButtonState);
  }
}


void setup() {
  
  // Setup hardware
  pinMode(statusLed, OUTPUT);
  digitalWrite(statusLed, LOW);
  pinMode(displayEnable, OUTPUT);
  digitalWrite(displayEnable, LOW);
  pinMode(buttonPush, INPUT);
  pinMode(buttonRotB, INPUT);
  pinMode(buttonRotA, INPUT);

  // Initialize the rotary state.
  lastRotaryState = getRotaryState();

  // Attach button interrupts
  attachInterrupt(digitalPinToInterrupt(buttonPush), processButtons, CHANGE);
  attachInterrupt(digitalPinToInterrupt(buttonRotB), processButtons, CHANGE);
  attachInterrupt(digitalPinToInterrupt(buttonRotA), processButtons, CHANGE);

  // Test all LEDs
  for (uint8_t i = 0; i < 4; ++i) {
    for (uint8_t j = 0; j < 4; ++j) {
      setLedEnabled(j, true);
      delay(50);
      setLedEnabled(j, false);
    }
  }

  // Enable the display.
  digitalWrite(displayEnable, HIGH);
  delay(500); // wait until the chip is ready.
  // Initialize the display library.
  lcd.begin(20, 4);
  // Increase the speed on the I2C bus.
  Wire.setClock(400000);
  // Enable the backlight.
  lcd.setBacklight(HIGH);

  // Write a welcome message.
  lcd.setCursor(3, 0);
  lcd.print("Lucky Resistor");
  lcd.setCursor(2, 1);
  lcd.print("Pet Feeder Demo");

  // Enable the green light
  setLedEnabled(0, true);

  // Set the position and enable a blinking cursor.
  lcd.setCursor(0, 3);
  lcd.cursor();
  lcd.blink();
}


void updateCounter(uint32_t value) 
{
  lcd.setCursor(0, 2);
  lcd.print(value);
  lcd.print("          ");
}


void writeInputEvent(char c)
{
  static uint8_t pos = 0;
  lcd.setCursor(pos, 3); 
  lcd.print(c);
  pos += 1;
  if (pos >= 20) {
    pos = 0;     
  }
  lcd.setCursor(pos, 3); 
}


void processInputs()
{
  auto input = getInput();
  while (input != Input::None) {
    if (input == Input::Push) {
      counter = 0;
      updateCounter(counter);
      writeInputEvent('P');
    } else if (input == Input::Left) {
      counter -= 1;
      updateCounter(counter);
      writeInputEvent('L');
    } else if (input == Input::Right) {
      counter += 1;
      updateCounter(counter);
      writeInputEvent('R');
    }
    input = getInput();
  }
}


void loop() {
  processInputs();
  delay(1);
}

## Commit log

2021-01-02 add all files for part 1
    [LR2051-101B.stl, LR2051-102B.stl, LR2051-103B.stl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]
2021-01-02 add bearing mockups
    [LR2051-821.f3d, LR2051-821.stl, LR2051-822.f3d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]
2021-01-12 Preparing the files for the next part
    [LR2051-404A.stl, LR2051-405A.stl, LR2051-406A.stl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]
2021-01-24 Adding the files for part 4.
    [LR2051-402A-E.stl, LR2051-402A-ND.stl, LR2051-402A.f3d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]
2021-01-24 Add the LED cover.
    [LR2051-422.stl]
2021-01-30 Adding the files for part 5.
    [LR2051-403A-E.stl, LR2051-403A.f3d, LR2051-403A.stl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]
2021-02-18 Adding the files for the 6. part of the series.
    [LR2051-421A.stl, LR2051-901-input-panel.brd, LR2051-901-input-panel.sch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]
2021-04-03 File updates for part 7 of the series.
    [LR2051-407A.stl, LR2051-411A.stl, LR2051-411B.stl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]
2021-04-05 Adding new file revisions for the turntable platform.
    [LR2051-407B.3mf, LR2051-407B.stl, LR2051-407E.3mf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]
